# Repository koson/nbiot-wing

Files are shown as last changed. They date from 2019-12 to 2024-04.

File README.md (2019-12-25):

# NBIoT Wing

This is a Feather "Wing" which can be added to any feather board. It works by sending AT commands over the RX/TX pins that are on D0/D1 of the feather board.

The NBIoT wing also has an optional USB port that allows it to be used as a stand-alone serial USB modem from your PC.

The wing features the BC66 modem by Quectel Wireless which features Cat NB1 LTE.

## Front

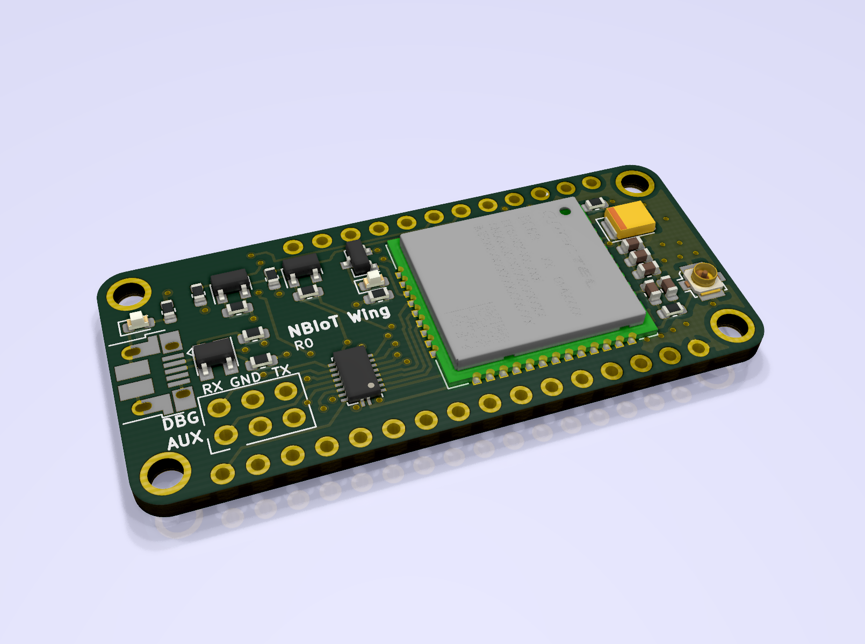
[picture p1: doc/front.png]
front


## Back

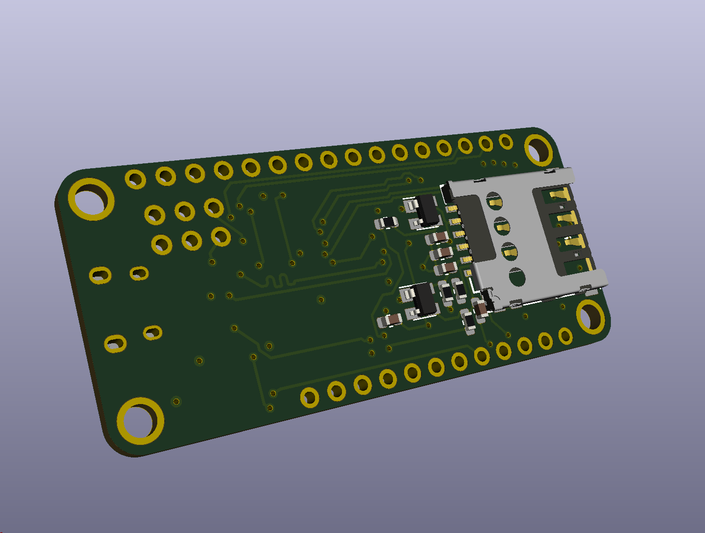
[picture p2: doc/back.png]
back


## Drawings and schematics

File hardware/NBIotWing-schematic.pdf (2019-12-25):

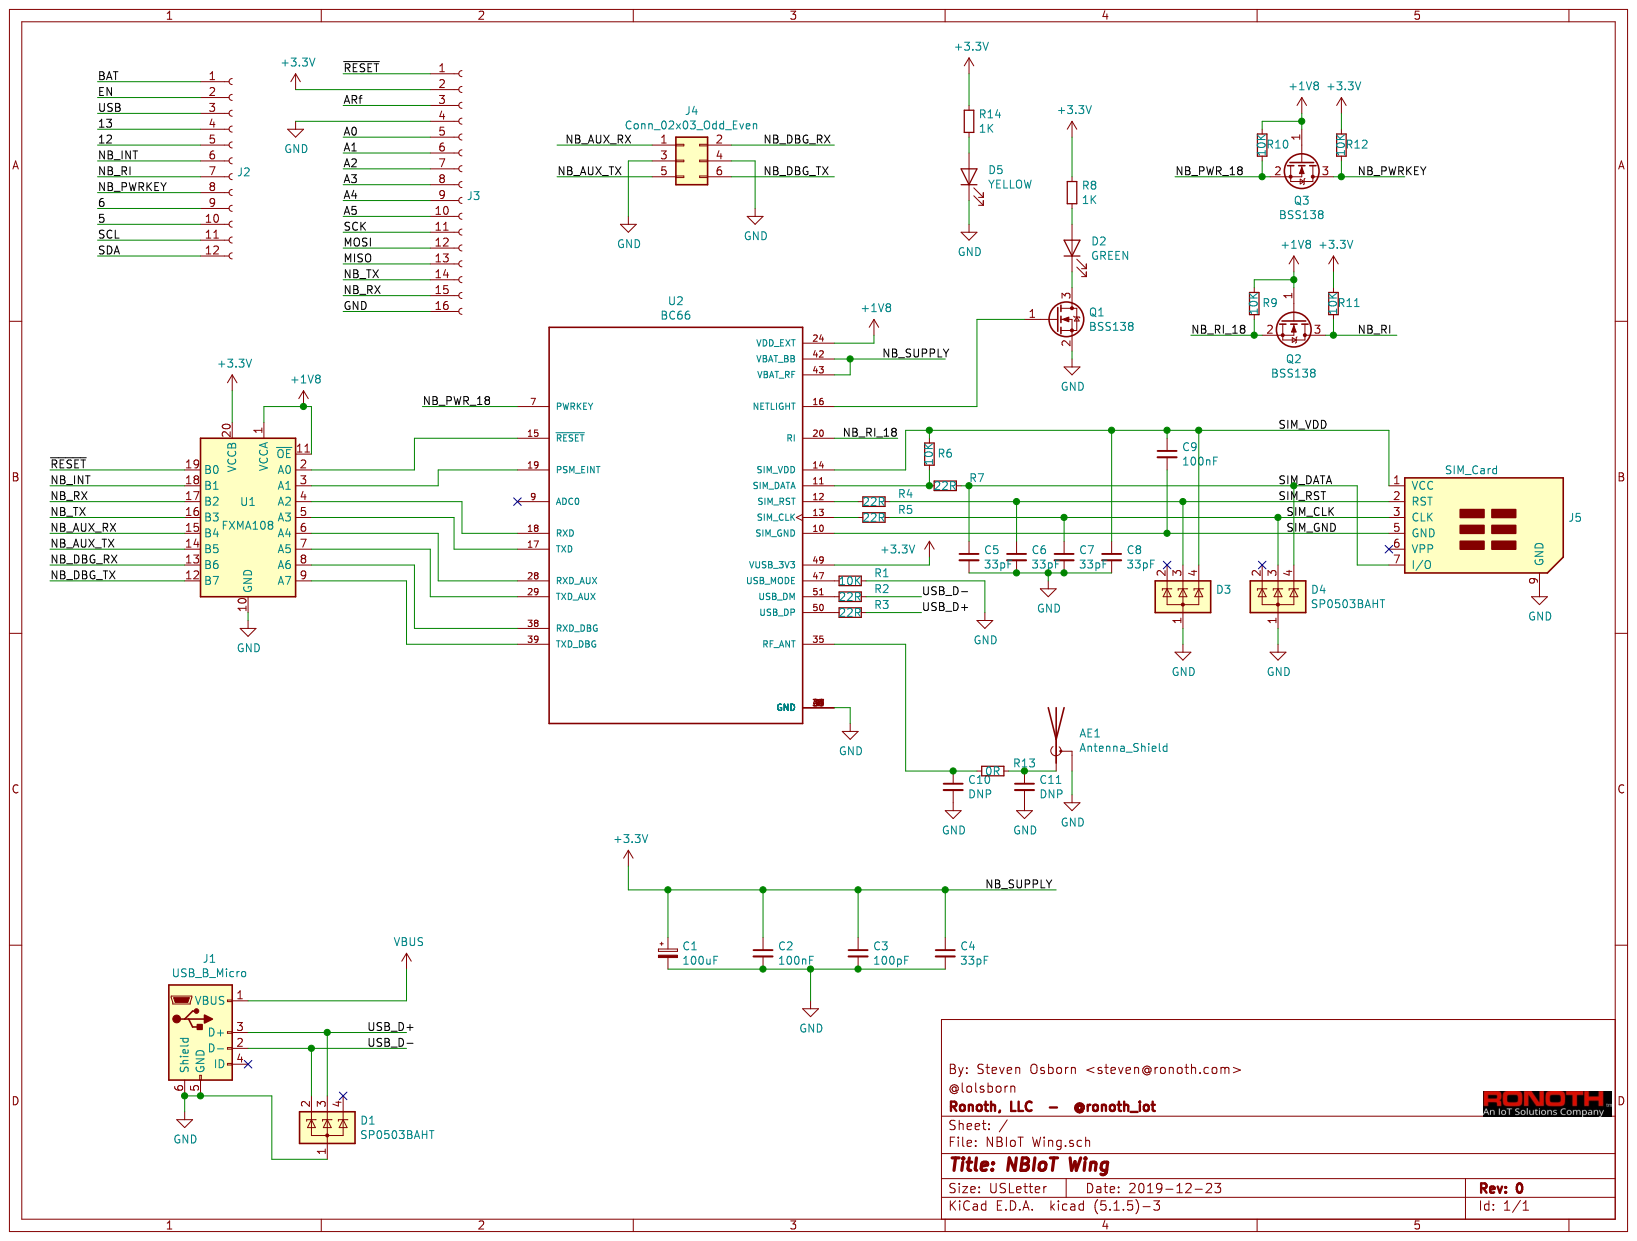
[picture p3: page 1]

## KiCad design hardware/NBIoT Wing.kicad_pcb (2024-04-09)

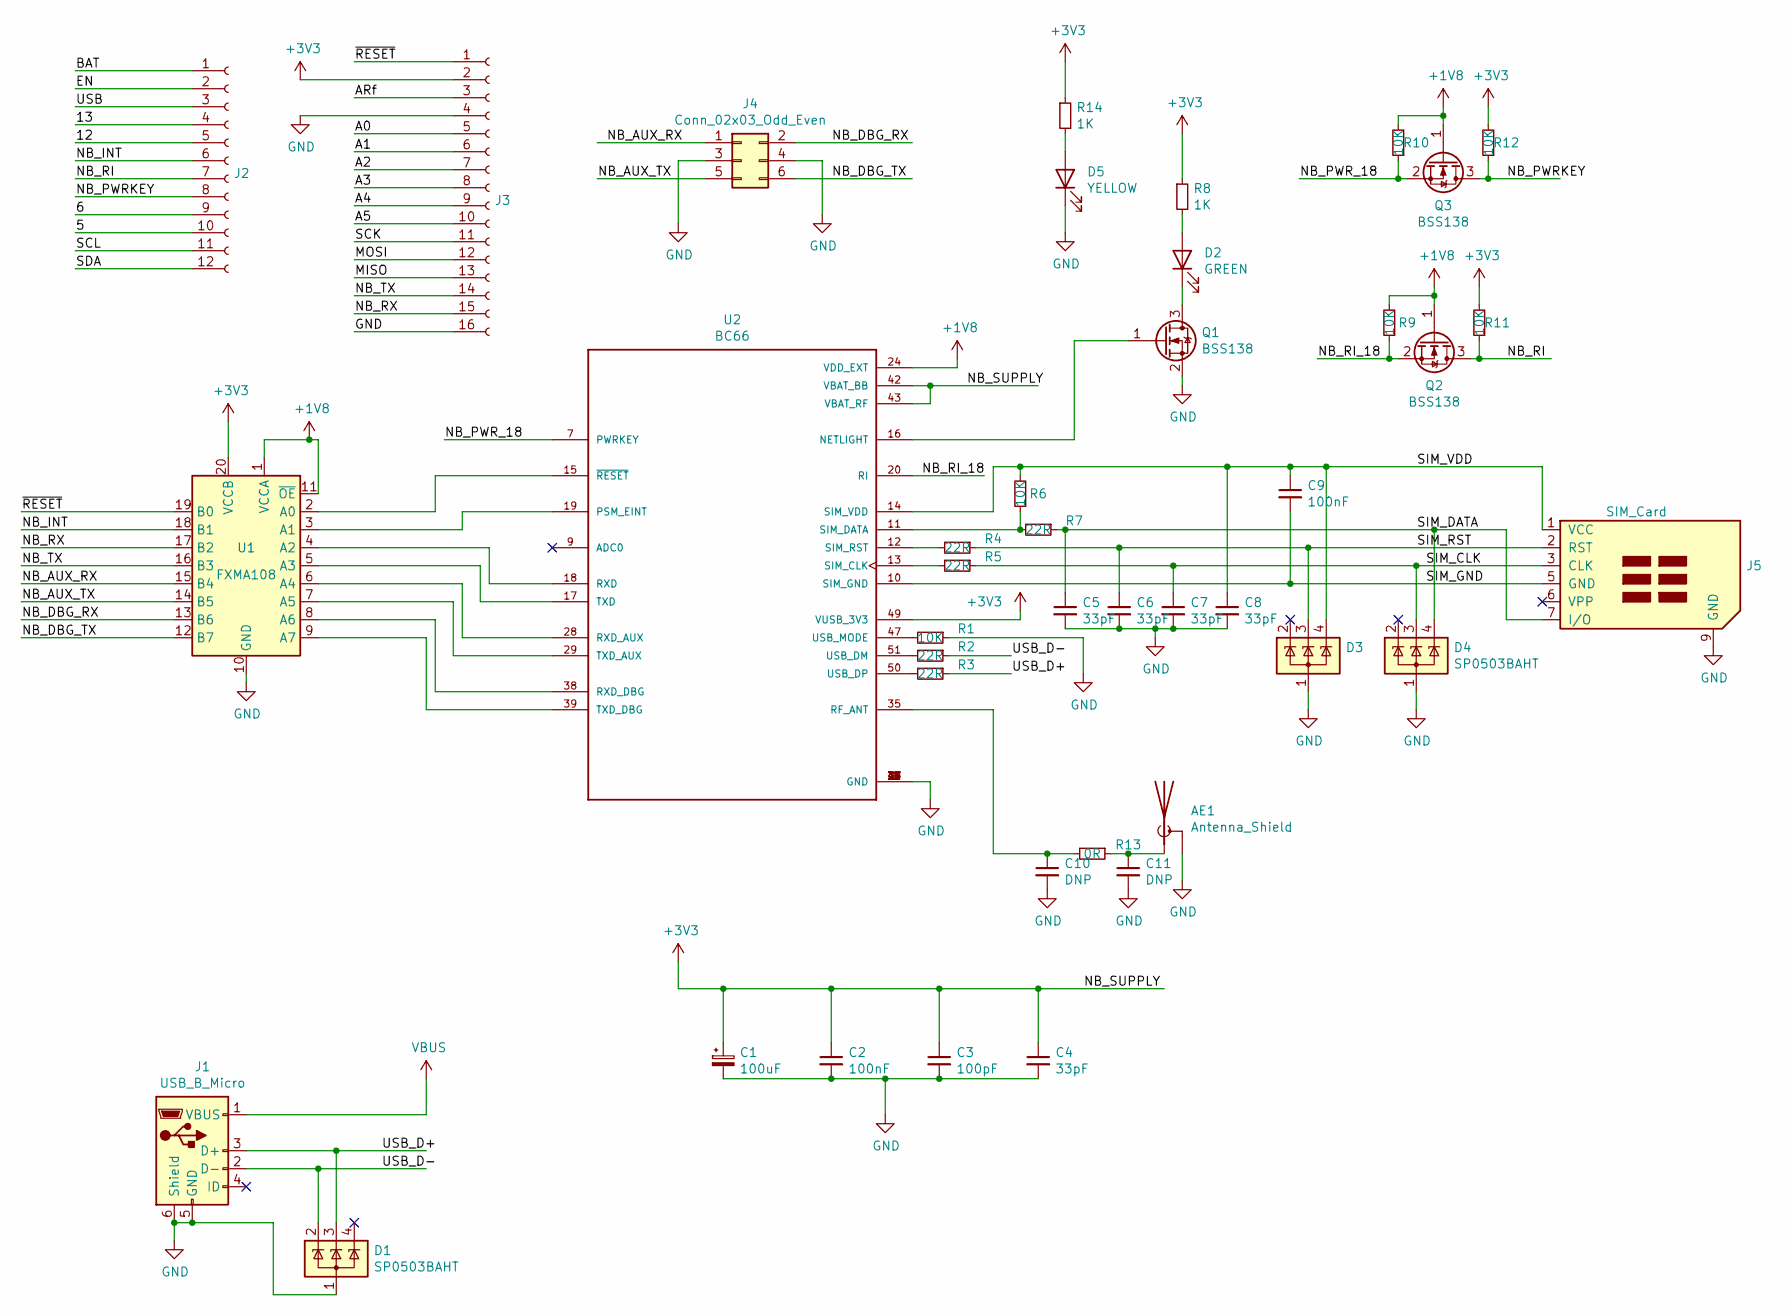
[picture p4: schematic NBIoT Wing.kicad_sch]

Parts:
AE1: Antenna_Shield; U.FL_Molex_MCRF_73412-0110_Vertical
C1: 100uF; CP_EIA-3528-12_Kemet-T
C2, C9: 100nF; C_0603_1608Metric
C3: 100pF; C_0603_1608Metric
C4, C5, C6, C7, C8: 33pF; C_0603_1608Metric
C10, C11: DNP; C_0603_1608Metric
D1, D3, D4: SP0503BAHT; SOT-143
D2: GREEN; LED_0603_1608Metric
D5: YELLOW; LED_0603_1608Metric
J1: USB_B_Micro; USB_Micro-B_Amphenol_10103594-0001LF_Horizontal
J2: Conn_01x12_Female; PinHeader_1x12_P2.54mm_Vertical
J3: Conn_01x16_Female; PinHeader_1x16_P2.54mm_Vertical
J4: Conn_02x03_Odd_Even; PinHeader_2x03_P2.54mm_Vertical
J5: SIM_Card; 0786463001
Q1, Q2, Q3: BSS138; SOT-23
R1, R6, R9, R10, R11, R12: 10K; R_0603_1608Metric
R2, R3, R4, R5, R7: 22R; R_0603_1608Metric
R8, R14: 1K; R_0603_1608Metric
R13: 0R; R_0603_1608Metric
U1: FXMA108; WQFN-20-1EP_2.5x4.5mm_P0.5mm_EP1x2.9mm
U2: BC66; XCVR_BC66

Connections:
+1V8: Q2.1 (G), Q3.1 (G), R9.2, R10.2, U1.1 (VCCA), U1.11 (~OE), U2.24 (VDD_EXT)
+3V3: C1.1, C2.1, C3.1, C4.1, J3.2, R8.1, R11.2, R12.2, R14.1, U1.20 (VCCB), U2.42 (VBAT_BB), U2.43 (VBAT_RF), U2.49 (VUSB_3V3)
/5: J2.10
/6: J2.9
/12: J2.5
/13: J2.4
/A0: J3.5
/A1: J3.6
/A2: J3.7
/A3: J3.8
/A4: J3.9
/A5: J3.10
/ARf: J3.3
/BAT: J2.1
/EN: J2.2
/MISO: J3.13
/MOSI: J3.12
/NB_AUX_RX: J4.1, U1.15 (B4)
/NB_AUX_TX: J4.5, U1.14 (B5)
/NB_DBG_RX: J4.2, U1.13 (B6)
/NB_DBG_TX: J4.6, U1.12 (B7)
/NB_INT: J2.6, U1.18 (B1)
/NB_PWRKEY: J2.8, Q3.3 (D), R12.1
/NB_PWR_18: Q3.2 (S), R10.1, U2.7 (PWRKEY)
/NB_RI: J2.7, Q2.3 (D), R11.1
/NB_RI_18: Q2.2 (S), R9.1, U2.20 (RI)
/NB_RX: J3.15, U1.17 (B2)
/NB_TX: J3.14, U1.16 (B3)
/SCK: J3.11
/SCL: J2.11
/SDA: J2.12
/SIM_CLK: C7.1, D4.3 (K), J5.3 (CLK), R5.1
/SIM_DATA: C5.1, D4.4 (K), J5.7 (I/O), R7.1
/SIM_GND: C9.2, J5.5 (GND), U2.10 (SIM_GND)
/SIM_RST: C6.1, D3.3 (K), J5.2 (RST), R4.1
/SIM_VDD: C8.1, C9.1, D3.4 (K), J5.1 (VCC), R6.2, U2.14 (SIM_VDD)
/USB: J2.3
/USB_D+: D1.3 (K), J1.3 (D+), R3.1
/USB_D-: D1.2 (K), J1.2 (D-), R2.1
/~RESET: J3.1, U1.19 (B0)
GND: AE1.2 (Shield), C1.2, C2.2, C3.2, C4.2, C5.2, C6.2, C7.2, C8.2, C10.2, C11.2, D1.1 (A), D3.1 (A), D4.1 (A), D5.1 (K), J1.5 (GND), J1.6 (Shield), J3.4, J3.16, J4.3, J4.4, J5.9 (GND), Q1.2 (S), R1.1, U1.10 (GND), U2.1 (GND), U2.27 (GND), U2.34 (GND), U2.36 (GND), U2.37 (GND), U2.40 (GND), U2.41 (GND)
unnamed: AE1.1 (A), C11.1, R13.1
unnamed: C10.1, R13.2, U2.35 (RF_ANT)
unnamed: D2.1 (K), Q1.3 (D)
unnamed: D2.2 (A), R8.2
unnamed: D5.2 (A), R14.2
unnamed: Q1.1 (G), U2.16 (NETLIGHT)
unnamed: R1.2, U2.47 (USB_MODE)
unnamed: R2.2, U2.51 (USB_DM)
unnamed: R3.2, U2.50 (USB_DP)
unnamed: R4.2, U2.12 (SIM_RST)
unnamed: R5.2, U2.13 (SIM_CLK)
unnamed: R6.1, R7.2, U2.11 (SIM_DATA)
unnamed: U1.2 (A0), U2.15 (~RESET)
unnamed: U1.3 (A1), U2.19 (PSM_EINT)
unnamed: U1.4 (A2), U2.18 (RXD)
unnamed: U1.5 (A3), U2.17 (TXD)
unnamed: U1.6 (A4), U2.28 (RXD_AUX)
unnamed: U1.7 (A5), U2.29 (TXD_AUX)
unnamed: U1.8 (A6), U2.38 (RXD_DBG)
unnamed: U1.9 (A7), U2.39 (TXD_DBG)
VBUS: J1.1 (VBUS)

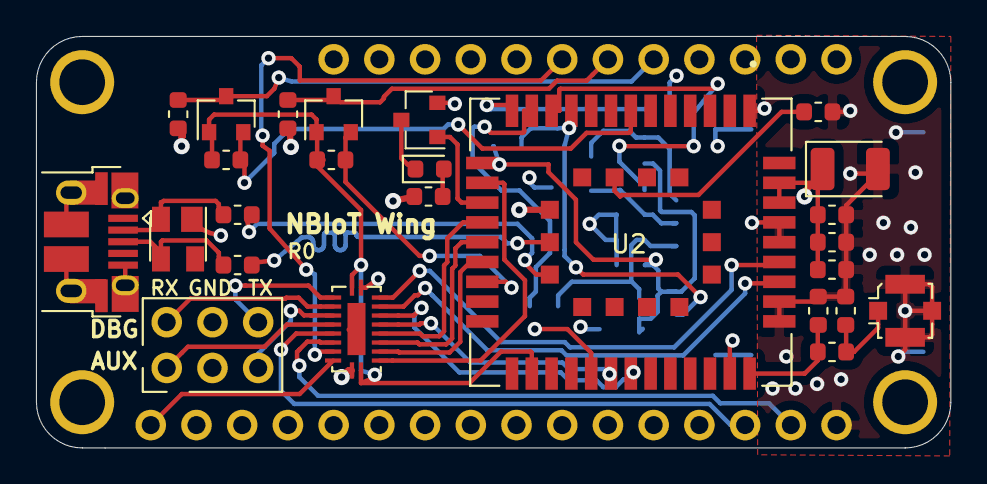
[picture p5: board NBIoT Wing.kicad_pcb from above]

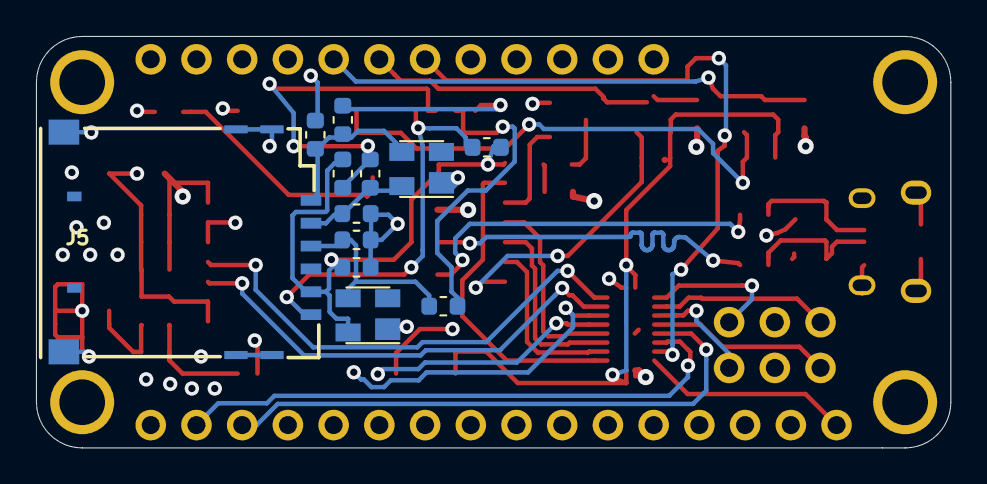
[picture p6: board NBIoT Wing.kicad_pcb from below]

Board: 4 copper layers, 50.8 x 22.9 mm, 40 parts (12 on the bottom side), 41 nets.

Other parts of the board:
PCB**: VAL**; PCB_FeatherWing

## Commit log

2019-12-29 BOM / gerbers
    [NBIoT Wing-B_Cu.gbr, NBIoT Wing-B_Mask.gbr, NBIoT Wing-B_Paste.gbr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]
2024-04-09 kicad 8
    [NBIoT Wing.kicad_pcb, NBIoT Wing.kicad_sch]
